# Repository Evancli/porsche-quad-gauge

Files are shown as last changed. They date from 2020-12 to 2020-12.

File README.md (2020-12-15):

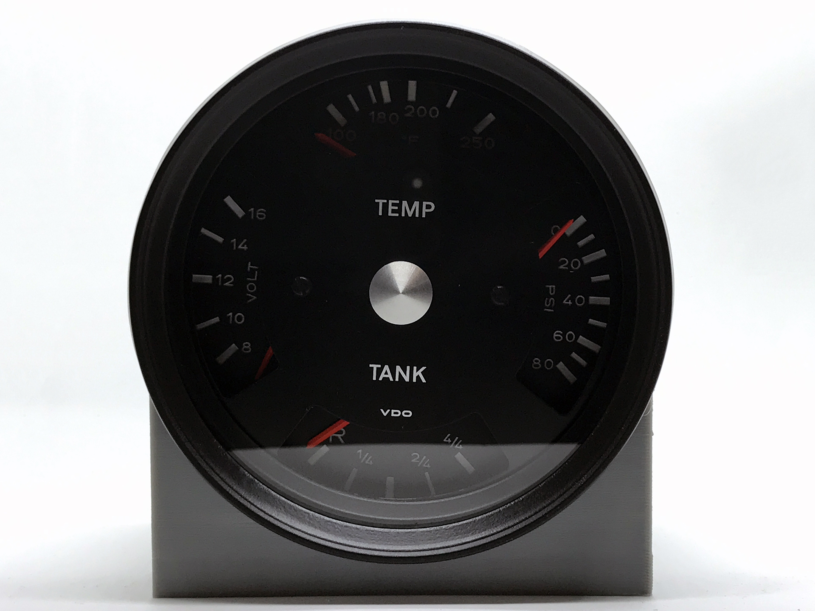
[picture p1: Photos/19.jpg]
Gauge


# QUAD GAUGE FOR A PORSCHE 914
More info [here](https://evanli.com/quad-gauge-for-a-porsche-914/).

## Required Items
This gauge uses salvaged components from a Porsche 944 fuel gauge; the bezel, glass, and face plate. You can used the vintage gauges from the 944 or the corresponding gauges from your 914. It also required two new VDO gauges for voltage and oil pressure.

## Disassembly Tips
It's quite laborious to open these VDO gauges, even with the right tools. A prying spudger and flat implement are needed. Lots of care and attention to not mess up the sheet metal. Be very careful when you pry open the 944 fuel gauge. It's very easy damage the surface finish of the bezel. 

## Processes
The build uses 3D printed parts as well a laser cut and etched parts. 

## License
Shield: [][cc-by-sa]

This work is licensed under a
[Creative Commons Attribution-ShareAlike 4.0 International License][cc-by-sa].

[][cc-by-sa]

[cc-by-sa]: http://creativecommons.org/licenses/by-sa/4.0/
[cc-by-sa-image]: https://licensebuttons.net/l/by-sa/4.0/88x31.png
[cc-by-sa-shield]: https://img.shields.io/badge/License-CC%20BY--SA%204.0-lightgrey.svg

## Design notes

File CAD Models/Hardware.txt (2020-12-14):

4X - 316 Stainless Steel Phillips Flat Head Screws 4-40 Thread Size, 5/16" Long McMaster #:  91500A124
8x - Tapered Heat-Set Inserts for Plastic 4-40 Thread Size, 0.135" Installed Length, Brass McMaster #: 93365A120

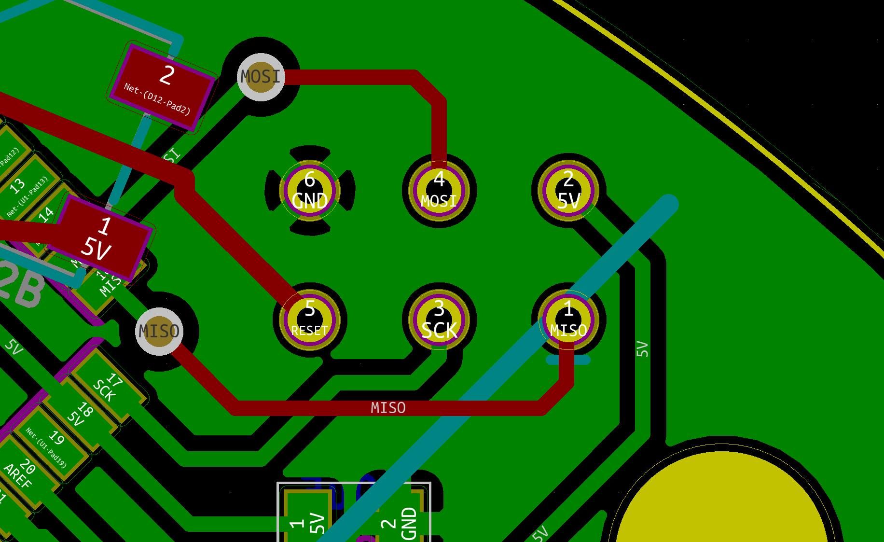
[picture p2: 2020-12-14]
Firmware/Programming Pinout.png

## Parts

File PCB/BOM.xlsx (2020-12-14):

Item # | Qty | Ref Des | Manufacturer | Manufacturer Part Num | Value | Package | Type | Digikey Part Num | Desciption
1 | 11 | QC Connector | TE Connectivity AMP Connectors | 63824-1 |  |  | Through Hole | A29938CT-ND | CONN QC TAB 0.250 SOLDER
2 | 6 | C1, C2, C3, C4, C5, C6 |  |  | 10uF | 0805 | SMT
3 | 1 | C7 |  |  | 0.1uF | 0805 | SMT
4 | 12 | D1, D2, D3, D4, D5, D6, D7, D8, D9, D10, D11, D12 |  | SK6812 RGBW LED |  |  | SMT
5 | 4 or 8 | Gauge Interface Pin (Depends on VDO Gauge Used) | Keystone Electronics | 1223 | 0.267"" (6.78mm) |  | Through Hole | 36-1223-ND | CONN PC PIN CIRC 0.093DIA NICKEL
6 | 4 or 8 | Gauge Interface Pin (Depends on VDO Gauge Used) | Keystone Electronics | 1224 | 0.331"" (8.41mm) |  | Through Hole | 36-1224-ND | CONN PC PIN CIRC 0.093DIA NICKEL
7 | 1 | OSC1 | Kyocera International Inc. | PRQC16.00CR5010X000 | 16MHz | 3-SMD, Non-Standard | SMT | 1253-1675-1-ND | CERAMIC RES 16.0000MHZ 10PF SMD
8 | 4 | R1, R2, R3, R4 |  |  | 1.2K Ohms 5% 1/8W | 0805 | SMT
9 | 3 | R5, R6, R7 |  |  | 1K Ohms 5% 1/8W | 0805 | SMT
10 | 1 | R8 |  |  | 10K Ohms 5% 1/8W | 0805 | SMT
11 | 1 | R9 |  |  | 1M Ohms 5% 1/8W | 0805 | SMT
12 | 4 | R10, R11, R12, R13 |  |  | 392 Ohms 5% 1/8W | 0805 | SMT
13 | 1 | U1 | Microchip Technology | ATMEGA328PB-ANR |  | 32-TQFP | SMT | ATMEGA328PB-ANRCT-ND | IC MCU 8BIT 32KB FLASH 32TQFP
14 | 1 | U2 | Toshiba Semiconductor and Storage | TLP290-4(GB,E) |  | 16-SOIC | SMT | TLP290-4(GBE)-ND | OPTOISOLTR 2.5KV 4CH TRANS 16-SO
15 | 1 | U3 | STMicroelectronics | L4941BDT-TR |  | DPAK | SMT | 497-1168-1-ND | IC REG LINEAR 5V 1A DPAK

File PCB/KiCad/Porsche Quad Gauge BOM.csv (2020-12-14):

Source: | C:\Users\evanc\Dropbox\Projects\Porsche\Quad Gauge\PCB\KiCad\Porsche Quad Gauge.sch
Date: | 12/14/2020 2:12:16 PM
Tool: | Eeschema (5.1.7)-1
Component Count: | 53
Ref | Value | Footprint | Datasheet | Manufacturer | Vendor
12V1 | CONNECTOR_QC_TAB_0.25 | Porsche Quad Gauge:CONNECTOR_QC_TAB-0.25
ALTERNATOR1 | CONNECTOR_QC_TAB_0.25 | Porsche Quad Gauge:CONNECTOR_QC_TAB-0.25
BRAKE_GND1 | CONNECTOR_QC_TAB_0.25 | Porsche Quad Gauge:CONNECTOR_QC_TAB-0.25
C1 | 10uF | Porsche Quad Gauge:0805
C2 | 10uF | Porsche Quad Gauge:0805
C3 | 10uF | Porsche Quad Gauge:0805
C4 | 10uF | Porsche Quad Gauge:0805
C5 | 10uF | Porsche Quad Gauge:0805
C6 | 10uF | Porsche Quad Gauge:0805
C7 | 0.1uF | Porsche Quad Gauge:0805
COOLANT_TEMP1 | CONNECTOR_QC_TAB_0.25 | Porsche Quad Gauge:CONNECTOR_QC_TAB-0.25
COOLANT_TEMP_GAUGE1 | VDO_OLD | Porsche Quad Gauge:VDO_GAUGE_SOCKET
D1 | WS2812B | Porsche Quad Gauge:WS2812B
D2 | WS2812B | Porsche Quad Gauge:WS2812B
D3 | WS2812B | Porsche Quad Gauge:WS2812B
D4 | WS2812B | Porsche Quad Gauge:WS2812B
D5 | WS2812B | Porsche Quad Gauge:WS2812B
D6 | WS2812B | Porsche Quad Gauge:WS2812B
D7 | WS2812B | Porsche Quad Gauge:WS2812B
D8 | WS2812B | Porsche Quad Gauge:WS2812B
D9 | WS2812B | Porsche Quad Gauge:WS2812B
D10 | WS2812B | Porsche Quad Gauge:WS2812B
D11 | WS2812B | Porsche Quad Gauge:WS2812B
D12 | WS2812B | Porsche Quad Gauge:WS2812B
FLASHER1 | CONNECTOR_QC_TAB_0.25 | Porsche Quad Gauge:CONNECTOR_QC_TAB-0.25
FUEL1 | CONNECTOR_QC_TAB_0.25 | Porsche Quad Gauge:CONNECTOR_QC_TAB-0.25
FUEL_GAUGE1 | VDO_OLD | Porsche Quad Gauge:VDO_GAUGE_SOCKET
FUEL_LOW1 | CONNECTOR_QC_TAB_0.25 | Porsche Quad Gauge:CONNECTOR_QC_TAB-0.25
GND1 | CONNECTOR_QC_TAB_0.25 | Porsche Quad Gauge:CONNECTOR_QC_TAB-0.25
J1 | AVR_SPI_PROG_3X2TESTPOINTS | Porsche Quad Gauge:2X3_TEST_POINTS
J2 | CONN_02 | Porsche Quad Gauge:1X02
LIGHT1 | CONNECTOR_QC_TAB_0.25 | Porsche Quad Gauge:CONNECTOR_QC_TAB-0.25
OIL_LOW1 | CONNECTOR_QC_TAB_0.25 | Porsche Quad Gauge:CONNECTOR_QC_TAB-0.25
OIL_PRESSURE1 | CONNECTOR_QC_TAB_0.25 | Porsche Quad Gauge:CONNECTOR_QC_TAB-0.25
OIL_PRESSURE_GAUGE1 | VDO_NEW | Porsche Quad Gauge:VDO_NEW_GAUGE_SOCKET
OSC1 | PRQC16.00SR1010V00L | Porsche Quad Gauge:3-SMD
R1 | 1.2K | Porsche Quad Gauge:0805
R2 | 1.2K | Porsche Quad Gauge:0805
R3 | 1.2K | Porsche Quad Gauge:0805
R4 | 1.2K | Porsche Quad Gauge:0805
R5 | 1k | Porsche Quad Gauge:0805
R6 | 1k | Porsche Quad Gauge:0805
R7 | 1k | Porsche Quad Gauge:0805
R8 | 10K | Porsche Quad Gauge:0805
R9 | 1M | Porsche Quad Gauge:0805
R10 | 392 | Porsche Quad Gauge:0805
R11 | 392 | Porsche Quad Gauge:0805
R12 | 392 | Porsche Quad Gauge:0805
R13 | 392 | Porsche Quad Gauge:0805
U1 | ATMEGA328P_TQFP | Porsche Quad Gauge:TQFP32-08
U2 | TLP290-4 | Porsche Quad Gauge:SO16
U3 | L4941BDT-TR | Porsche Quad Gauge:D-PAK_TO252AA
VOLTAGE_GAUGE1 | VDO_NEW | Porsche Quad Gauge:VDO_NEW_GAUGE_SOCKET

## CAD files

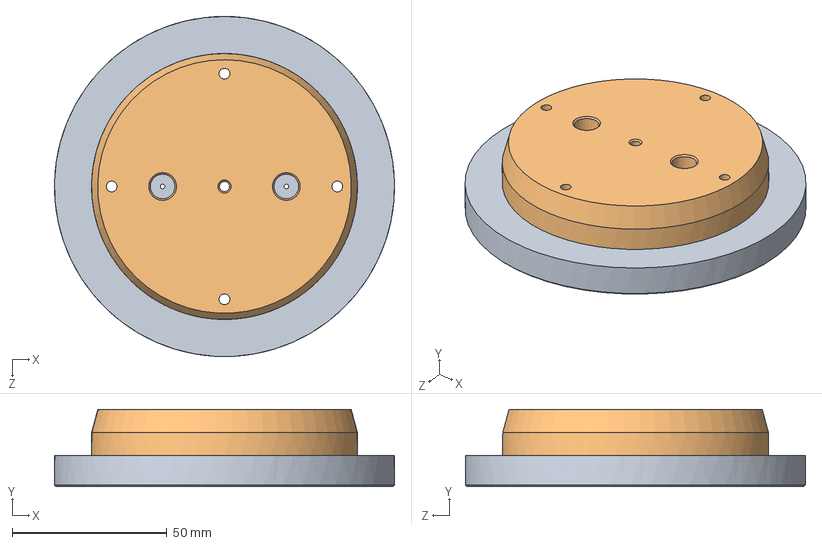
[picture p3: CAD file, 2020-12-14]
Tooling/SLD/Jig.SLDASM
110.0 x 25.0 x 110.0 mm
Jig Base
Drill Jig 3mm

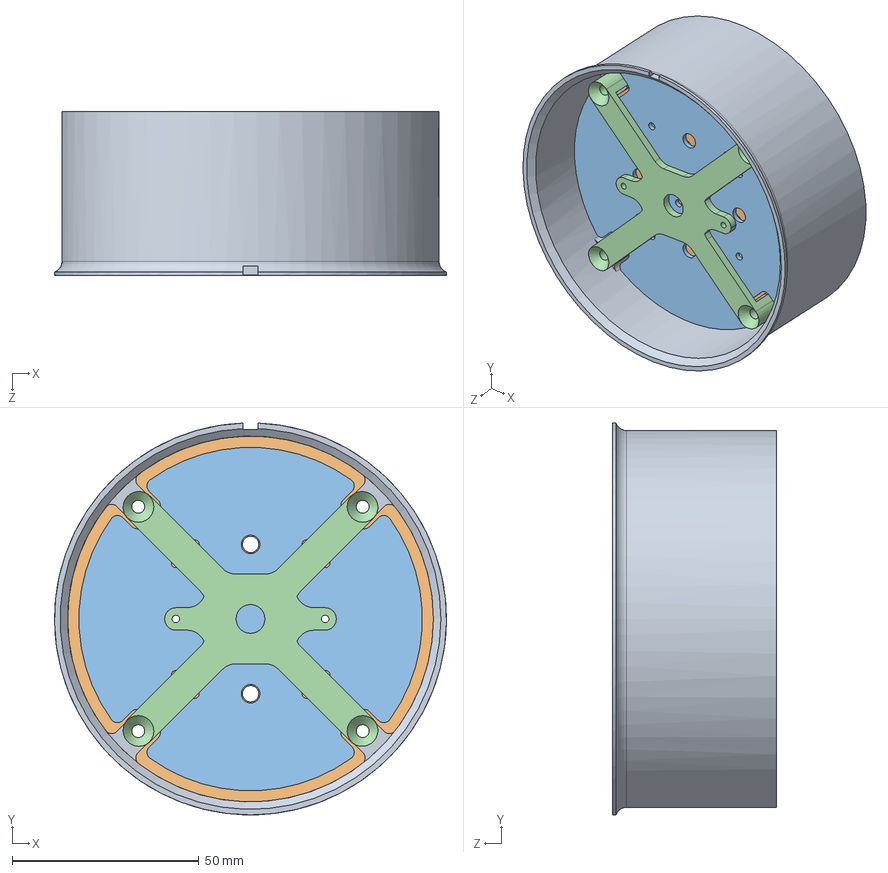
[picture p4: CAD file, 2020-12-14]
CAD Models/SLD/Gauge.SLDASM
105.0 x 105.0 x 44.0 mm
Gauge Shell
PCB
Marking Panel
Panel Mount

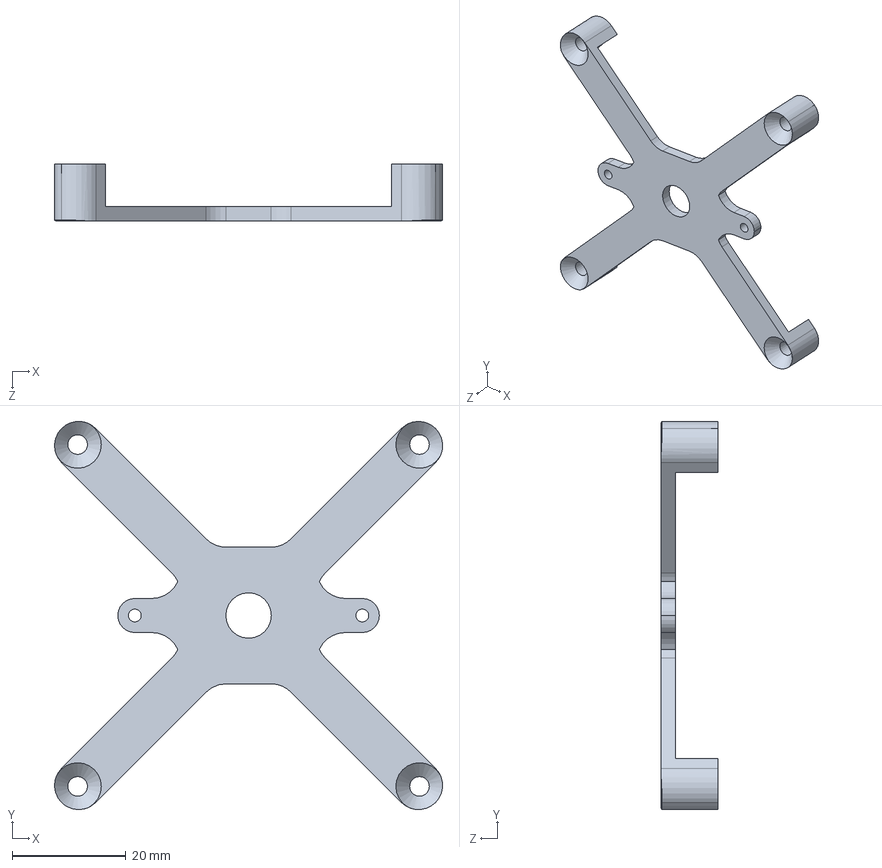
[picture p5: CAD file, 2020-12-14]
CAD Models/SLD/Panel Mount.SLDPRT
68.2 x 68.3 x 10.0 mm

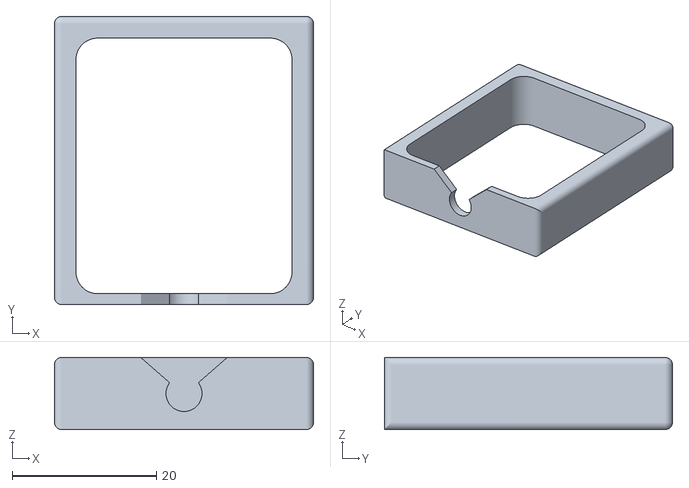
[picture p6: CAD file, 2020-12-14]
Tooling/STL/Needle Puller.STL
36.0 x 40.0 x 10.0

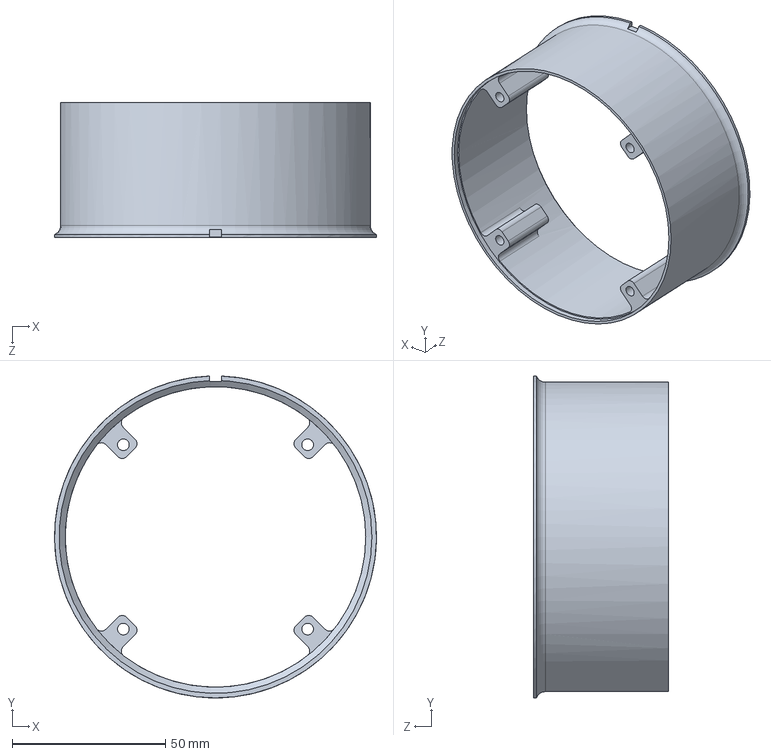
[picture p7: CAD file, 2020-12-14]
CAD Models/SLD/Gauge Shell.SLDPRT
105.0 x 105.0 x 44.0 mm

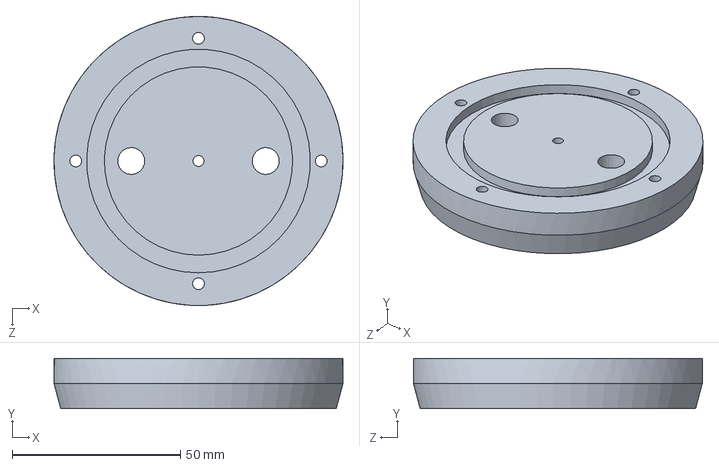
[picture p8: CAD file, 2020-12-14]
Tooling/SLD/Drill Jig 3mm.SLDPRT
86.0 x 15.0 x 86.0 mm

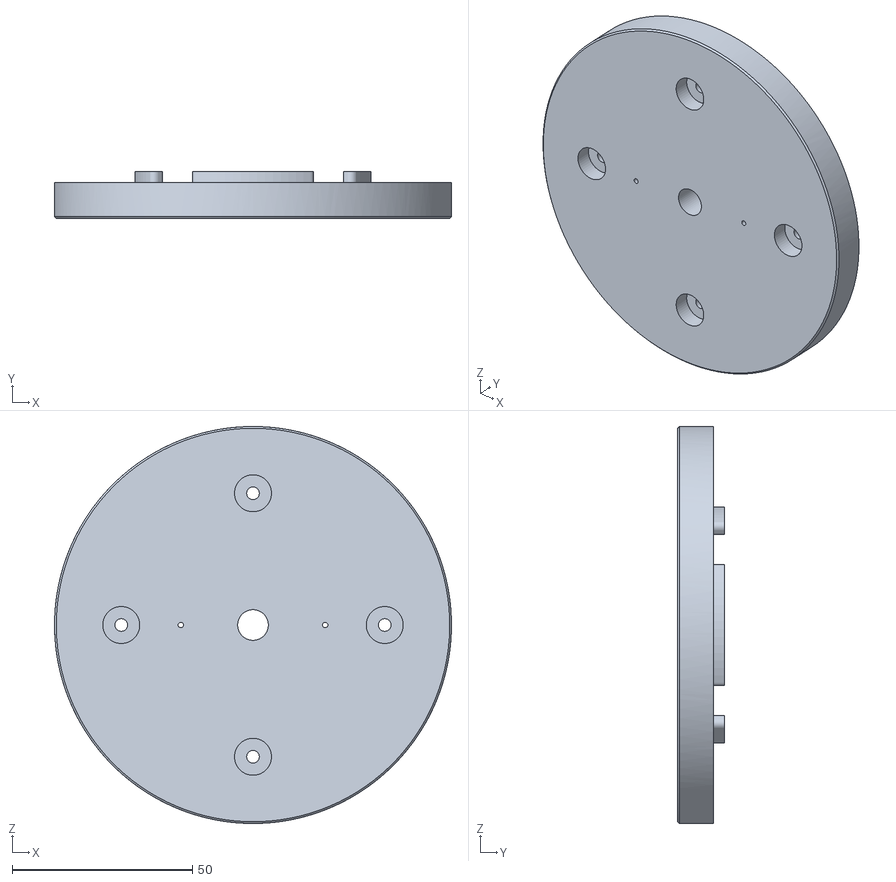
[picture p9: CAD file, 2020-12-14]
Tooling/STL/Jig Base.STL
110.0 x 13.0 x 110.0

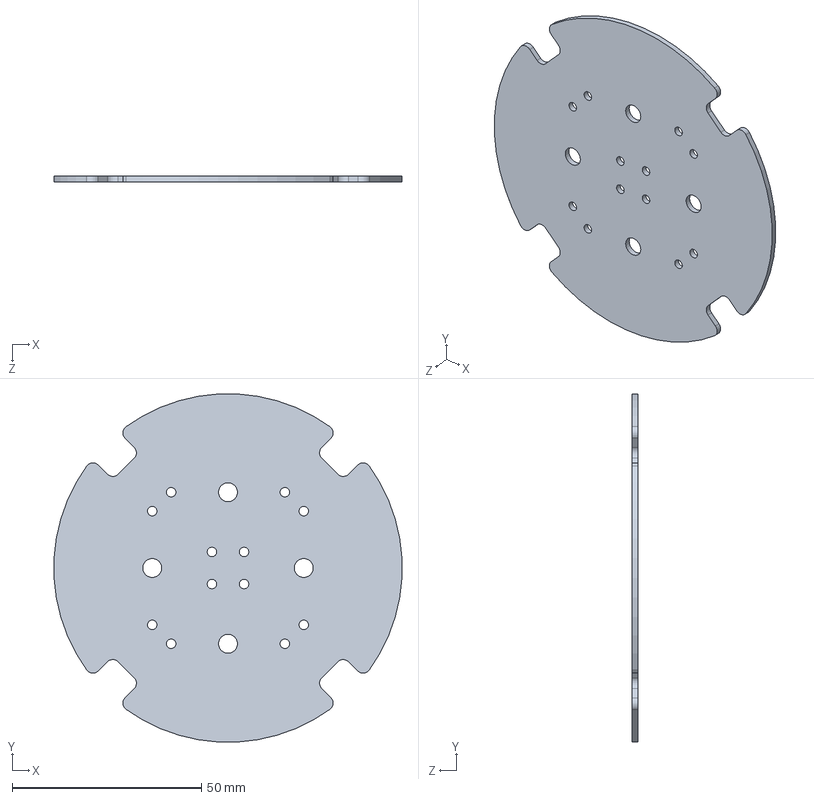
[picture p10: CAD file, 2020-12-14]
CAD Models/SLD/Marking Panel.SLDPRT
91.9 x 91.9 x 1.50 mm

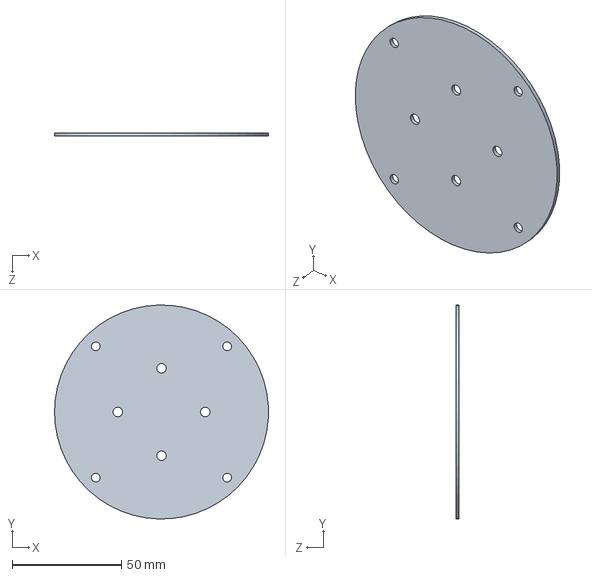
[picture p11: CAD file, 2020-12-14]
CAD Models/SLD/PCB.SLDPRT
98.0 x 98.0 x 1.60 mm

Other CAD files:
CAD Models/STL/Panel Mount v0.3.STL
CAD Models/STL/Gauge Shell v0.5.STL
Tooling/SLD/Jig Base.SLDPRT
Tooling/STL/Drill Jig 7mm.STL
Tooling/SLD/Needle Puller.SLDPRT
Tooling/STL/Drill Jig 3mm.STL
Tooling/SLD/Drill Jig 7mm.SLDPRT

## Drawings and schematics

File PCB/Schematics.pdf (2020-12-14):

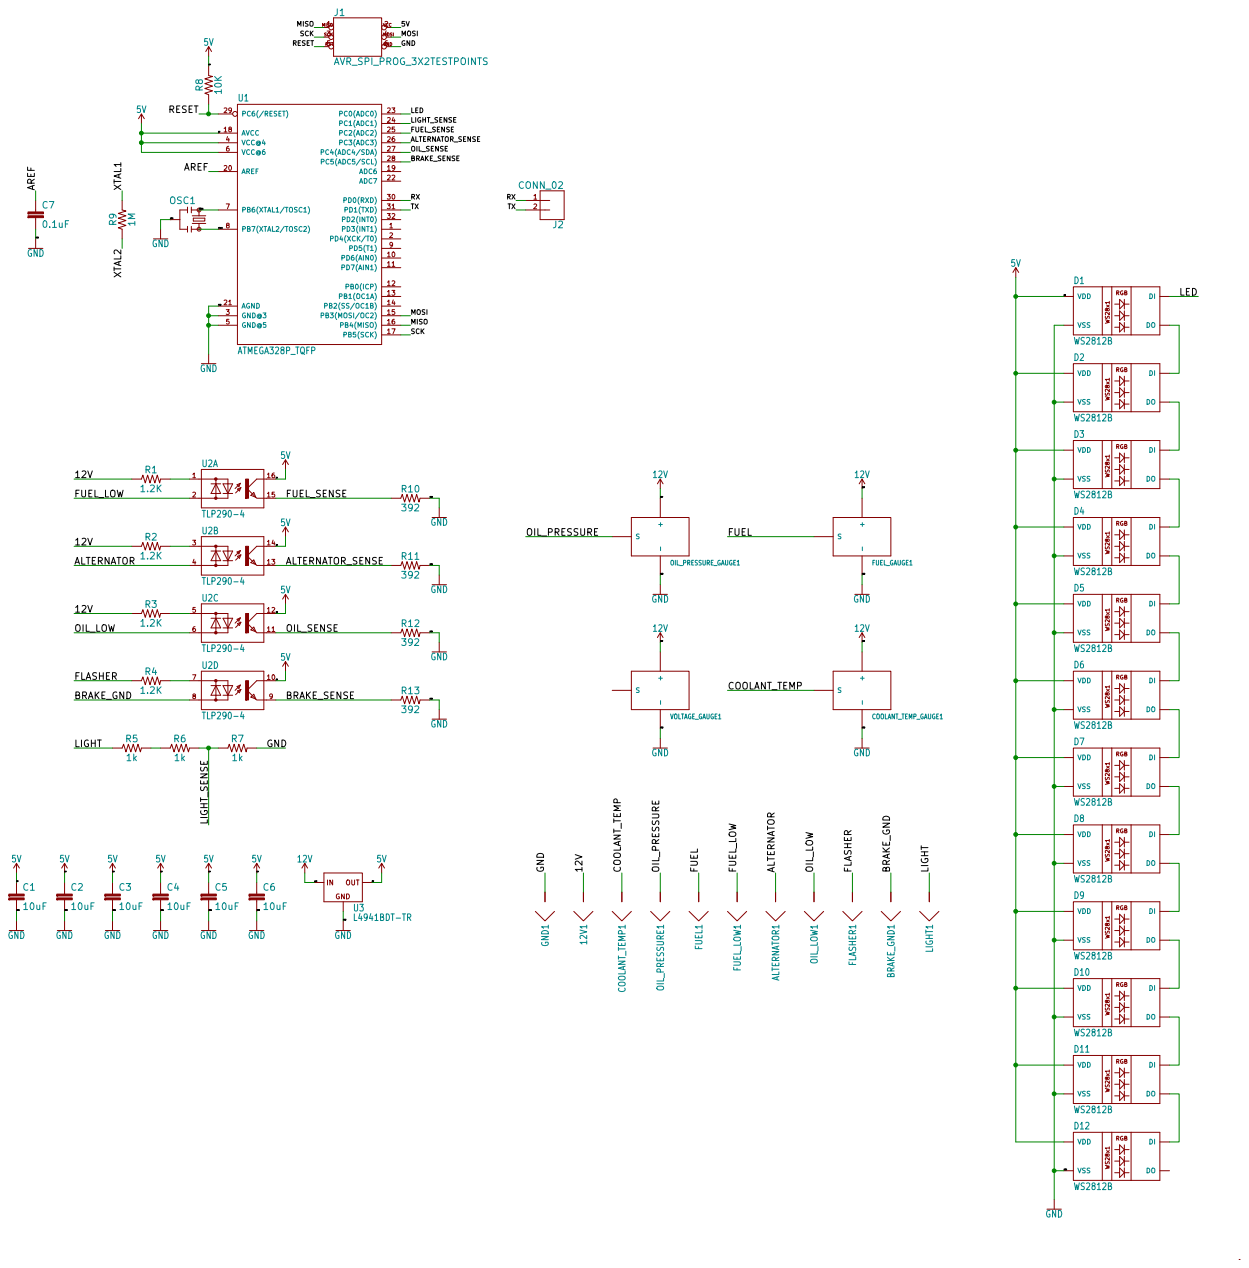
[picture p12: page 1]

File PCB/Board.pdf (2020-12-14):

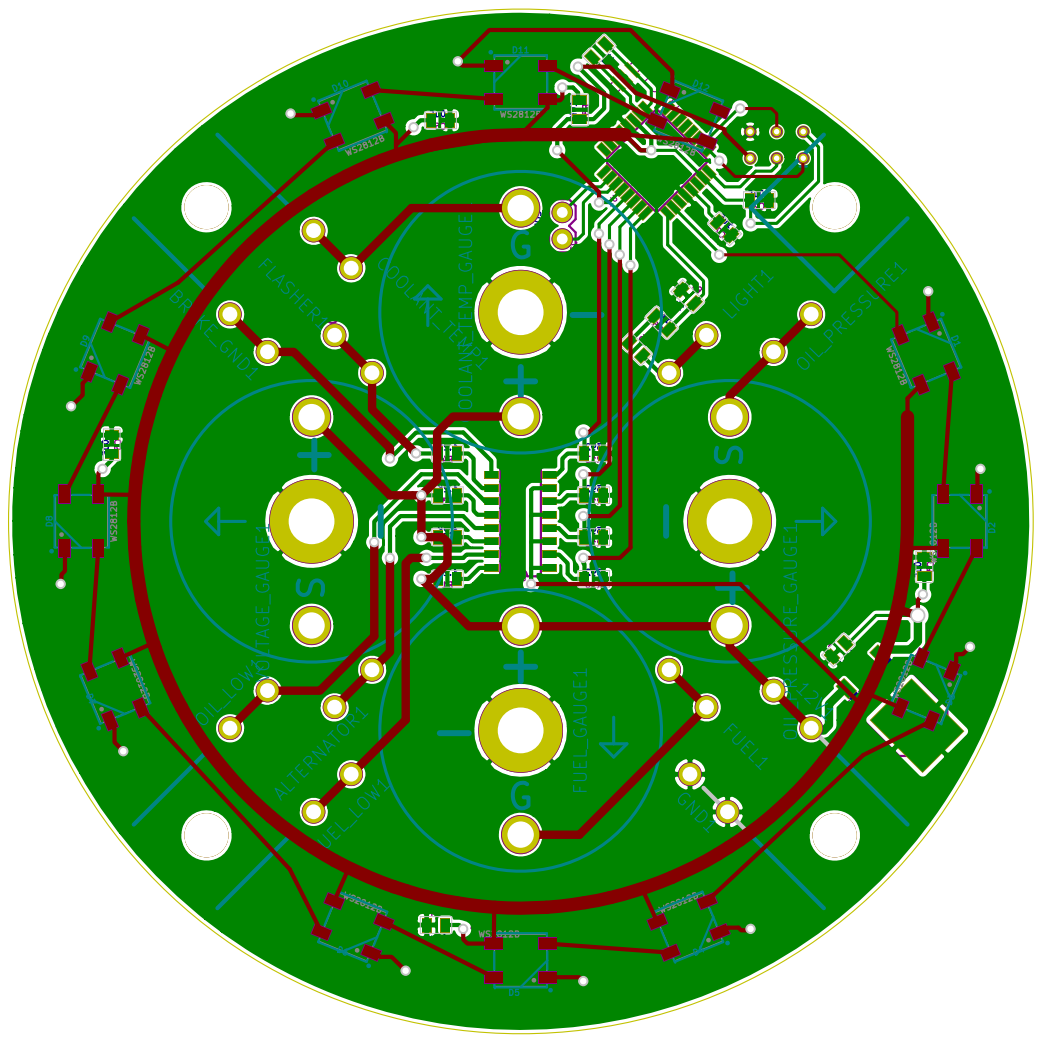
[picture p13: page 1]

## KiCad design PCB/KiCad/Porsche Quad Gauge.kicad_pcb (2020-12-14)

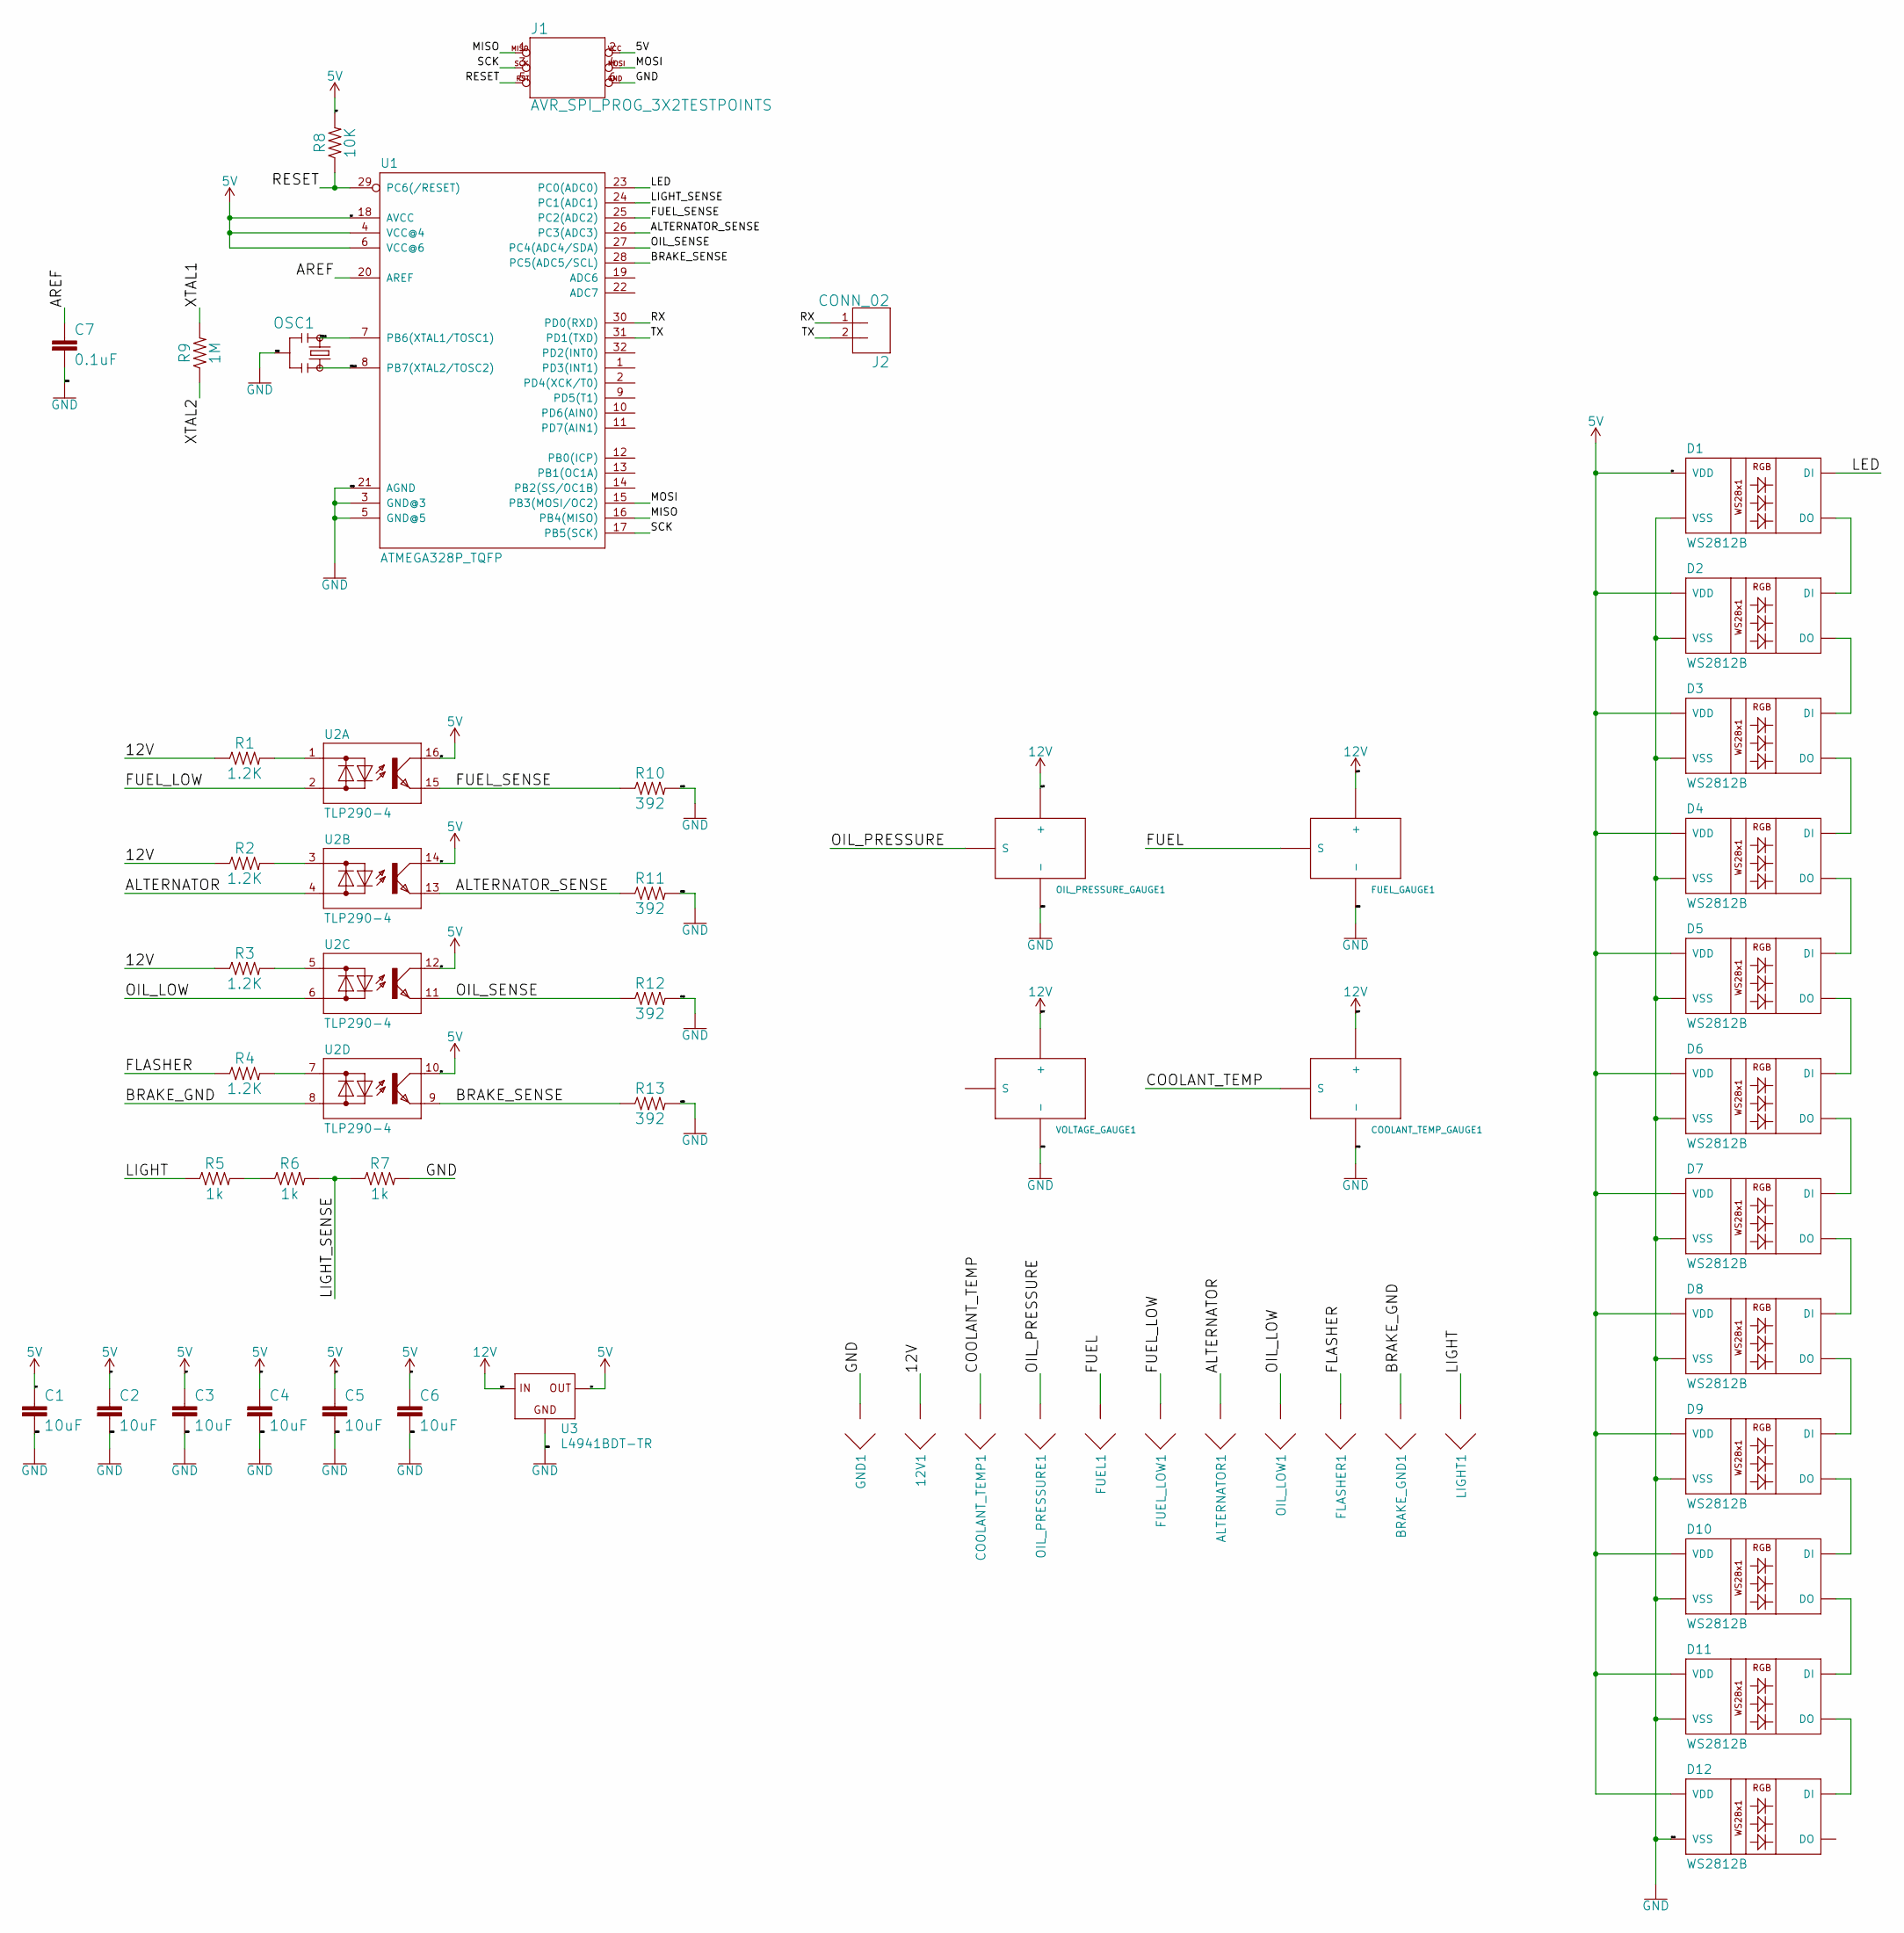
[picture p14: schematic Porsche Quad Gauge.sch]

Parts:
12V1: CONNECTOR_QC_TAB_0.25; CONNECTOR_QC_TAB-0.25
ALTERNATOR1: CONNECTOR_QC_TAB_0.25; CONNECTOR_QC_TAB-0.25
BRAKE_GND1: CONNECTOR_QC_TAB_0.25; CONNECTOR_QC_TAB-0.25
C1, C2, C3, C4, C5, C6: 10uF; 0805
C7: 0.1uF; 0805
COOLANT_TEMP1: CONNECTOR_QC_TAB_0.25; CONNECTOR_QC_TAB-0.25
COOLANT_TEMP_GAUGE1: VDO_OLD; VDO_GAUGE_SOCKET
D1, D2, D3, D4, D5, D6, D7, D8, D9, D10, D11, D12: WS2812B
FLASHER1: CONNECTOR_QC_TAB_0.25; CONNECTOR_QC_TAB-0.25
FUEL1: CONNECTOR_QC_TAB_0.25; CONNECTOR_QC_TAB-0.25
FUEL_GAUGE1: VDO_OLD; VDO_GAUGE_SOCKET
FUEL_LOW1: CONNECTOR_QC_TAB_0.25; CONNECTOR_QC_TAB-0.25
GND1: CONNECTOR_QC_TAB_0.25; CONNECTOR_QC_TAB-0.25
J1: AVR_SPI_PROG_3X2TESTPOINTS; 2X3_TEST_POINTS
J2: CONN_02; 1X02
LIGHT1: CONNECTOR_QC_TAB_0.25; CONNECTOR_QC_TAB-0.25
OIL_LOW1: CONNECTOR_QC_TAB_0.25; CONNECTOR_QC_TAB-0.25
OIL_PRESSURE1: CONNECTOR_QC_TAB_0.25; CONNECTOR_QC_TAB-0.25
OIL_PRESSURE_GAUGE1: VDO_NEW; VDO_NEW_GAUGE_SOCKET
OSC1: PRQC16.00SR1010V00L; 3-SMD
R1, R2, R3, R4: 1.2K; 0805
R5, R6, R7: 1k; 0805
R8: 10K; 0805
R9: 1M; 0805
R10, R11, R12, R13: 392; 0805
U1: ATMEGA328P_TQFP; TQFP32-08
U2: TLP290-4; SO16
U3: L4941BDT-TR; D-PAK_TO252AA
VOLTAGE_GAUGE1: VDO_NEW; VDO_NEW_GAUGE_SOCKET

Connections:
5V: C1.1, C2.1, C3.1, C4.1, C5.1, C6.1, D1.1 (VDD), D2.1 (VDD), D3.1 (VDD), D4.1 (VDD), D5.1 (VDD), D6.1 (VDD), D7.1 (VDD), D8.1 (VDD), D9.1 (VDD), D10.1 (VDD), D11.1 (VDD), D12.1 (VDD), J1.2, R8.2, U1.4 (VCC@4), U1.6 (VCC@6), U1.18 (AVCC), U2.10 (C), U2.12 (C), U2.14 (C), U2.16 (C), U3.3 (OUT)
12V: 12V1.S1, 12V1.S2, COOLANT_TEMP_GAUGE1.12V (+), FUEL_GAUGE1.12V (+), OIL_PRESSURE_GAUGE1.12V (+), R1.1, R2.1, R3.1, U3.1 (IN), VOLTAGE_GAUGE1.12V (+)
/ALTERNATOR: ALTERNATOR1.S1, ALTERNATOR1.S2, U2.4 (AC2)
/ALTERNATOR_SENSE: R11.1, U1.26 (PC3(ADC3)), U2.13 (E)
/AREF: C7.1, U1.20 (AREF)
/BRAKE_GND: BRAKE_GND1.S1, BRAKE_GND1.S2, U2.8 (AC2)
/BRAKE_SENSE: R13.1, U1.28 (PC5(ADC5/SCL)), U2.9 (E)
/COOLANT_TEMP: COOLANT_TEMP1.S1, COOLANT_TEMP1.S2, COOLANT_TEMP_GAUGE1.SIGNAL (S)
/FLASHER: FLASHER1.S1, FLASHER1.S2, R4.1
/FUEL: FUEL1.S1, FUEL1.S2, FUEL_GAUGE1.SIGNAL (S)
/FUEL_LOW: FUEL_LOW1.S1, FUEL_LOW1.S2, U2.2 (AC2)
/FUEL_SENSE: R10.1, U1.25 (PC2(ADC2)), U2.15 (E)
/LED: D1.4 (DI), U1.23 (PC0(ADC0))
/LIGHT: LIGHT1.S1, LIGHT1.S2, R5.1
/LIGHT_SENSE: R6.2, R7.1, U1.24 (PC1(ADC1))
/MISO: J1.1, U1.16 (PB4(MISO))
/MOSI: J1.4, U1.15 (PB3(MOSI/OC2))
/OIL_LOW: OIL_LOW1.S1, OIL_LOW1.S2, U2.6 (AC2)
/OIL_PRESSURE: OIL_PRESSURE1.S1, OIL_PRESSURE1.S2, OIL_PRESSURE_GAUGE1.SIGNAL (S)
/OIL_SENSE: R12.1, U1.27 (PC4(ADC4/SDA)), U2.11 (E)
/RESET: J1.5, R8.1, U1.29 (PC6(/RESET))
/RX: J2.1, U1.30 (PD0(RXD))
/SCK: J1.3, U1.17 (PB5(SCK))
/TX: J2.2, U1.31 (PD1(TXD))
/XTAL1: OSC1.XTAL1 (1), R9.2, U1.7 (PB6(XTAL1/TOSC1))
/XTAL2: OSC1.XTAL2 (3), R9.1, U1.8 (PB7(XTAL2/TOSC2))
GND: C1.2, C2.2, C3.2, C4.2, C5.2, C6.2, C7.2, COOLANT_TEMP_GAUGE1.GND (-), D1.3 (VSS), D2.3 (VSS), D3.3 (VSS), D4.3 (VSS), D5.3 (VSS), D6.3 (VSS), D7.3 (VSS), D8.3 (VSS), D9.3 (VSS), D10.3 (VSS), D11.3 (VSS), D12.3 (VSS), FUEL_GAUGE1.GND (-), GND1.S1, GND1.S2, J1.6, OIL_PRESSURE_GAUGE1.GND (-), OSC1.GND (2), R7.2, R10.2, R11.2, R12.2, R13.2, U1.3 (GND@3), U1.5 (GND@5), U1.21 (AGND), U3.2 (GND), VOLTAGE_GAUGE1.GND (-)
unnamed: D1.2 (DO), D2.4 (DI)
unnamed: D2.2 (DO), D3.4 (DI)
unnamed: D3.2 (DO), D4.4 (DI)
unnamed: D4.2 (DO), D5.4 (DI)
unnamed: D5.2 (DO), D6.4 (DI)
unnamed: D6.2 (DO), D7.4 (DI)
unnamed: D7.2 (DO), D8.4 (DI)
unnamed: D8.2 (DO), D9.4 (DI)
unnamed: D10.2 (DO), D11.4 (DI)
unnamed: D9.2 (DO), D10.4 (DI)
unnamed: D11.2 (DO), D12.4 (DI)
unnamed: R1.2, U2.1 (AC1)
unnamed: R2.2, U2.3 (AC1)
unnamed: R3.2, U2.5 (AC1)
unnamed: R4.2, U2.7 (AC1)
unnamed: R5.2, R6.1

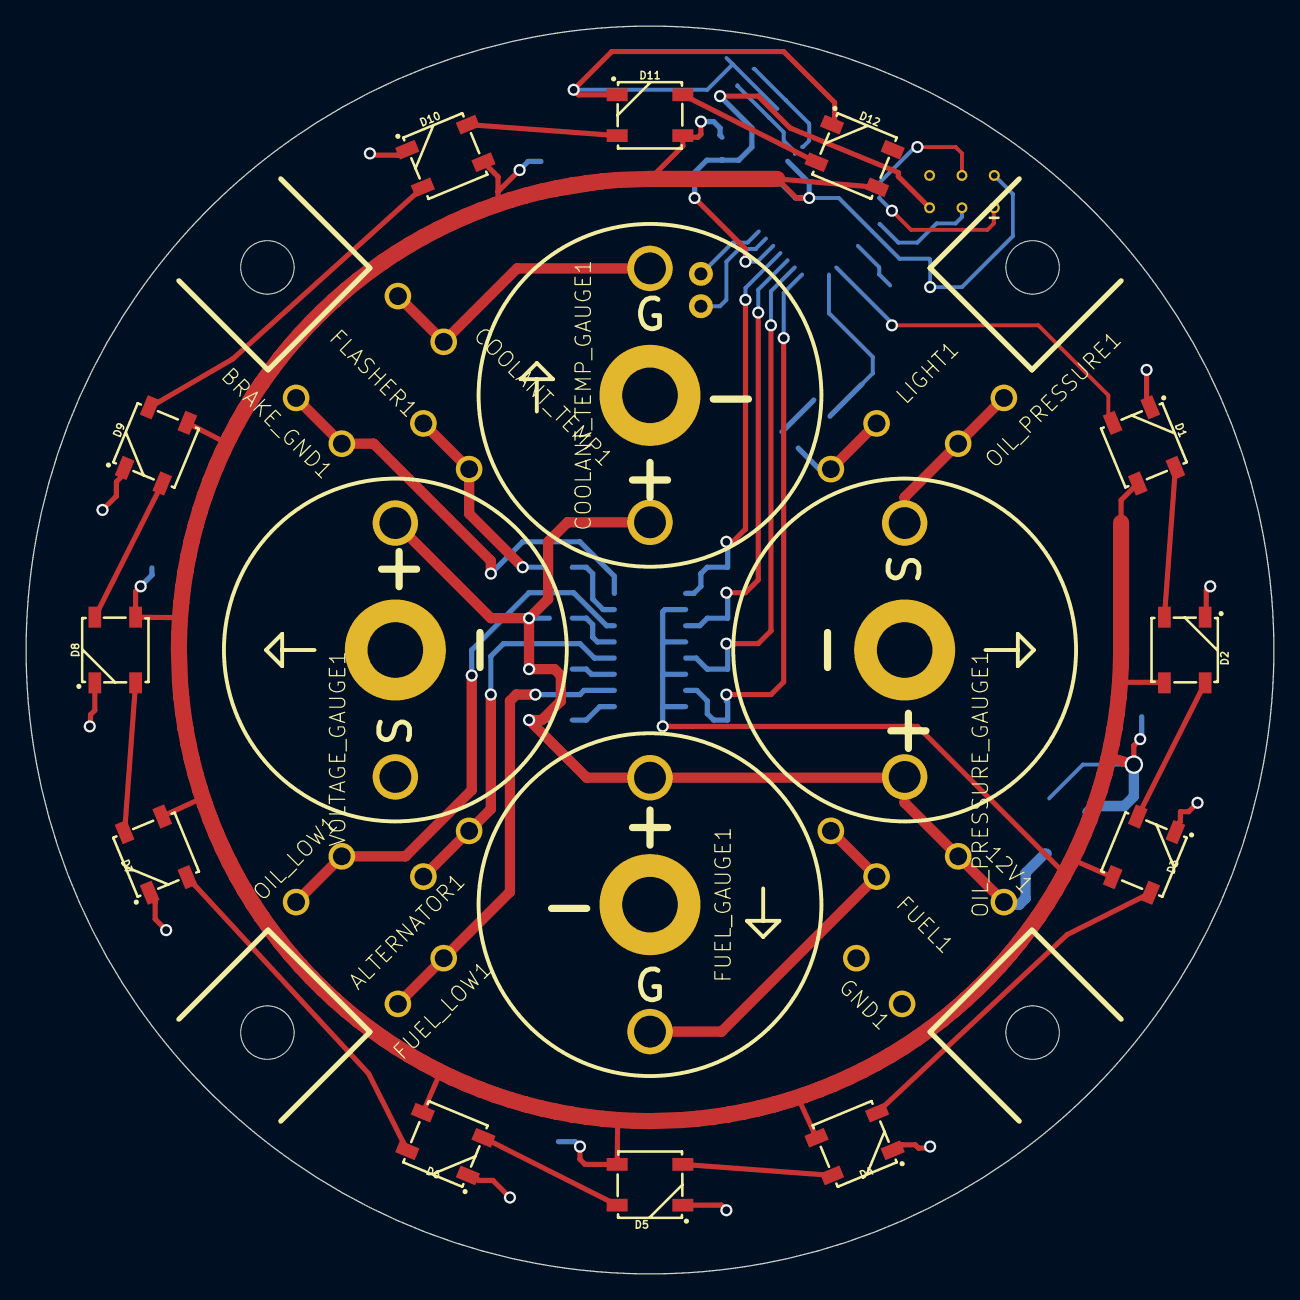
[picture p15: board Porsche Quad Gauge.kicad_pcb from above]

Board: 2 copper layers, 98.0 x 98.0 mm, 57 parts (0 on the bottom side), 43 nets.

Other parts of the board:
@HOLE0, @HOLE1, @HOLE2, @HOLE3: (no value)

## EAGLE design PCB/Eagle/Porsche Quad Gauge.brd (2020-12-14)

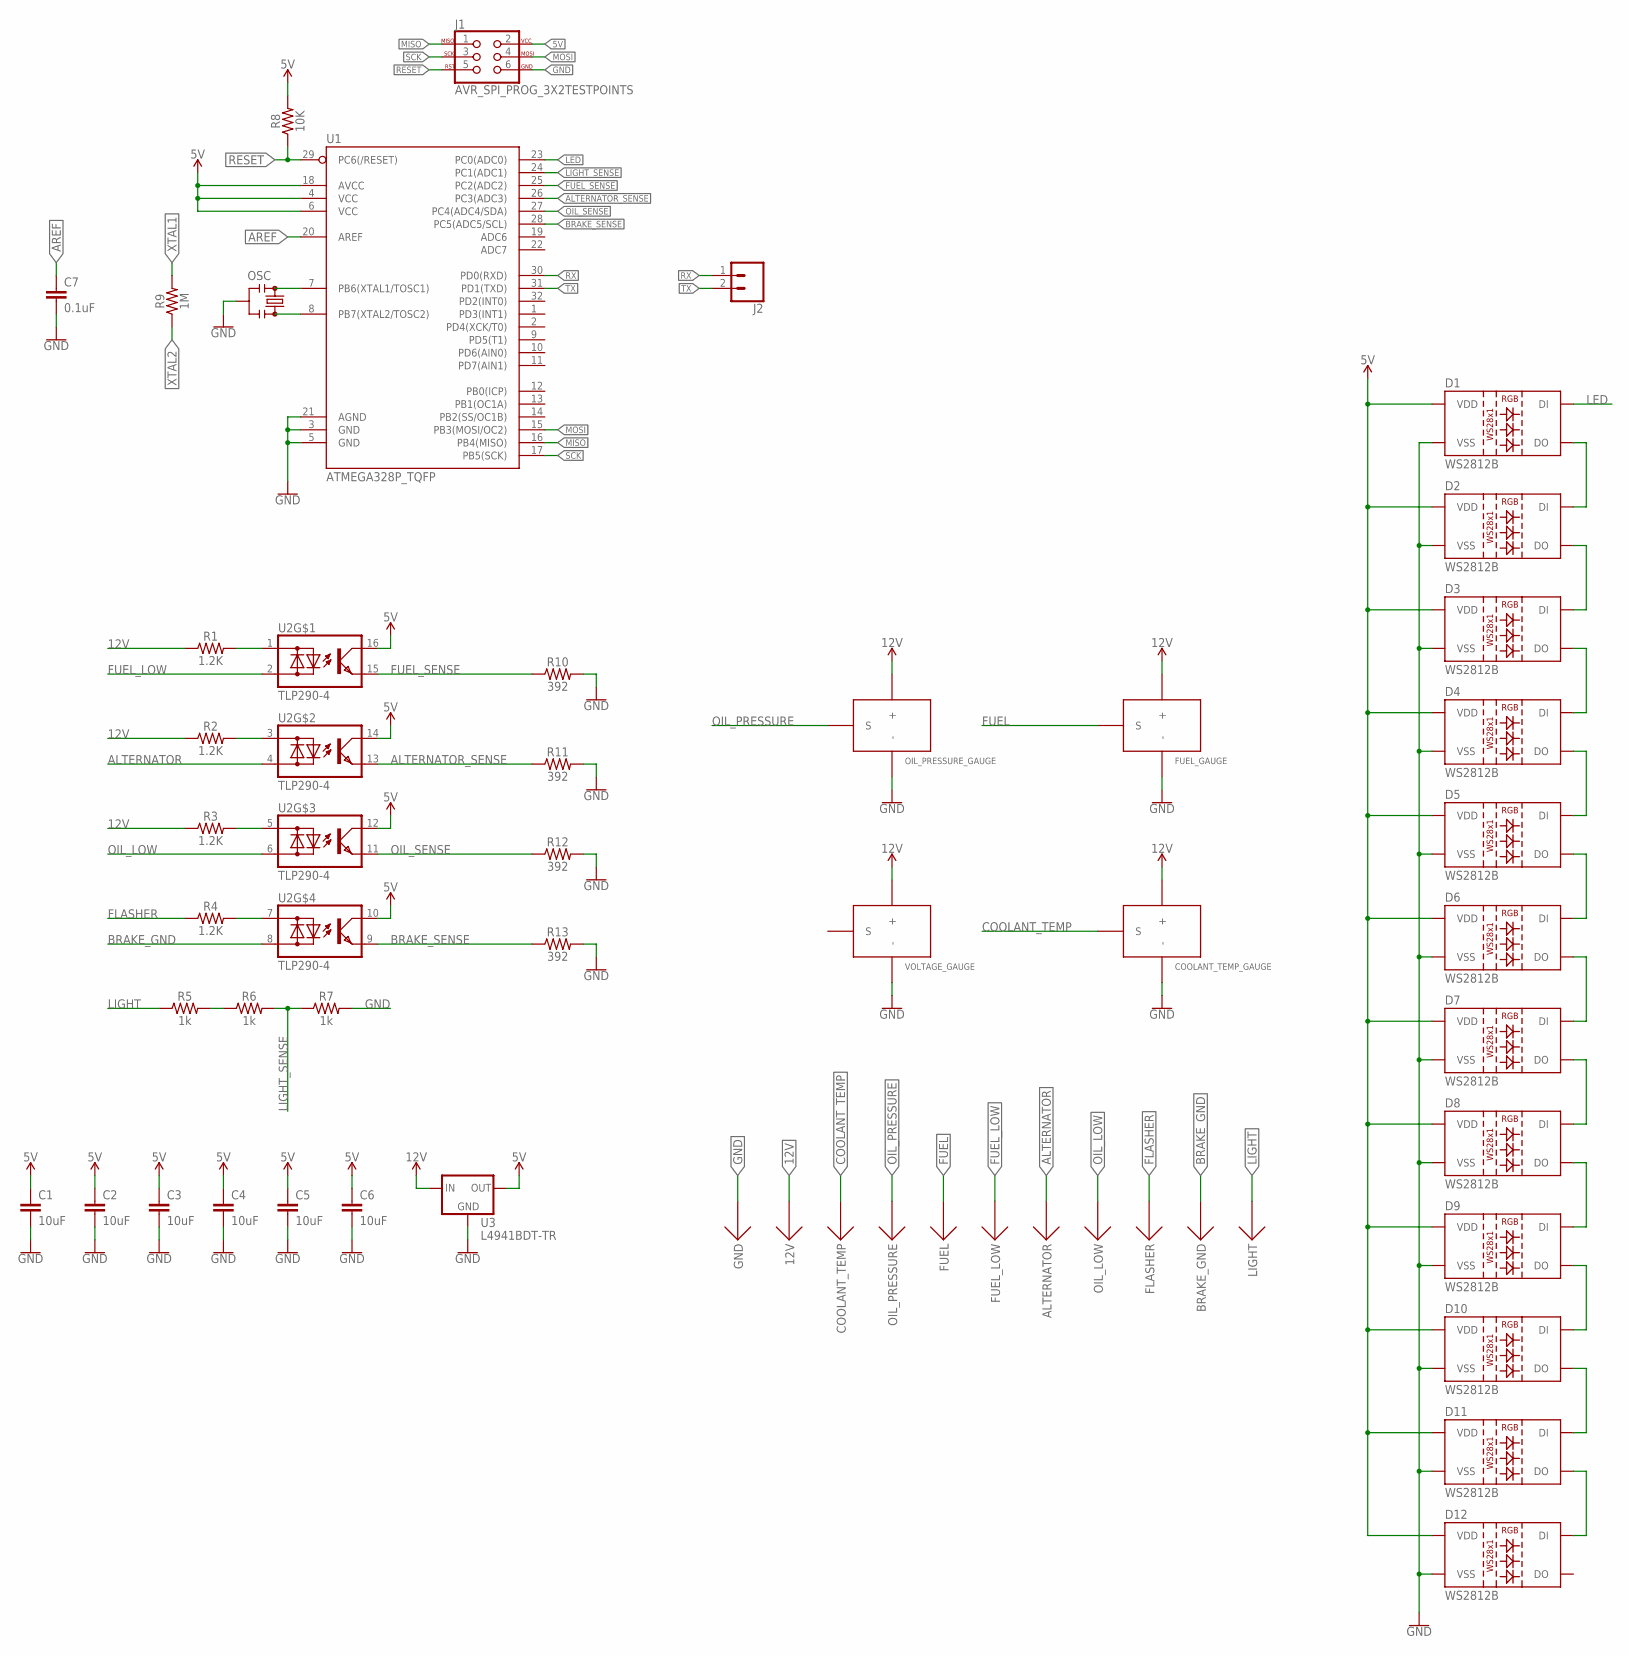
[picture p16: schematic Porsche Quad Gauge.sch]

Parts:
12V: CONNECTOR_QC_TAB_0.25; CONNECTOR_QC_TAB-0.25
ALTERNATOR: CONNECTOR_QC_TAB_0.25; CONNECTOR_QC_TAB-0.25
BRAKE_GND: CONNECTOR_QC_TAB_0.25; CONNECTOR_QC_TAB-0.25
C1, C2, C3, C4, C5, C6: 10uF; 0805
C7: 0.1uF; 0805
COOLANT_TEMP: CONNECTOR_QC_TAB_0.25; CONNECTOR_QC_TAB-0.25
COOLANT_TEMP_GAUGE: VDO_OLD; VDO_GAUGE_SOCKET
D1, D2, D3, D4, D5, D6, D7, D8, D9, D10, D11, D12: WS2812B
FLASHER: CONNECTOR_QC_TAB_0.25; CONNECTOR_QC_TAB-0.25
FUEL: CONNECTOR_QC_TAB_0.25; CONNECTOR_QC_TAB-0.25
FUEL_GAUGE: VDO_OLD; VDO_GAUGE_SOCKET
FUEL_LOW: CONNECTOR_QC_TAB_0.25; CONNECTOR_QC_TAB-0.25
GND: CONNECTOR_QC_TAB_0.25; CONNECTOR_QC_TAB-0.25
J1: AVR_SPI_PROG_3X2TESTPOINTS; 2X3_TEST_POINTS
J2: CONN_02; 1X02
LIGHT: CONNECTOR_QC_TAB_0.25; CONNECTOR_QC_TAB-0.25
OIL_LOW: CONNECTOR_QC_TAB_0.25; CONNECTOR_QC_TAB-0.25
OIL_PRESSURE: CONNECTOR_QC_TAB_0.25; CONNECTOR_QC_TAB-0.25
OIL_PRESSURE_GAUGE: VDO_NEW; VDO_NEW_GAUGE_SOCKET
OSC: PRQC16.00SR1010V00L; 3-SMD
R1, R2, R3, R4: 1.2K; 0805
R5, R6, R7: 1k; 0805
R8: 10K; 0805
R9: 1M; 0805
R10, R11, R12, R13: 392; 0805
U1: ATMEGA328P_TQFP; TQFP32-08
U2: TLP290-4; SO16
U3: L4941BDT-TR; D-PAK_TO252AA
VOLTAGE_GAUGE: VDO_NEW; VDO_NEW_GAUGE_SOCKET

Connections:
5V: C1.1, C2.1, C3.1, C4.1, C5.1, C6.1, D1.1 (VDD), D2.1 (VDD), D3.1 (VDD), D4.1 (VDD), D5.1 (VDD), D6.1 (VDD), D7.1 (VDD), D8.1 (VDD), D9.1 (VDD), D10.1 (VDD), D11.1 (VDD), D12.1 (VDD), J1.2, R8.2, U1.4 (VCC), U1.6 (VCC), U1.18 (AVCC), U2.10 (C), U2.12 (C), U2.14 (C), U2.16 (C), U3.3 (OUT)
12V: 12V.S1, 12V.S2, COOLANT_TEMP_GAUGE.12V (+), FUEL_GAUGE.12V (+), OIL_PRESSURE_GAUGE.12V (+), R1.1, R2.1, R3.1, U3.1 (IN), VOLTAGE_GAUGE.12V (+)
ALTERNATOR: ALTERNATOR.S1, ALTERNATOR.S2, U2.4 (AC2)
ALTERNATOR_SENSE: R11.1, U1.26 (PC3(ADC3)), U2.13 (E)
AREF: C7.1, U1.20 (AREF)
BRAKE_GND: BRAKE_GND.S1, BRAKE_GND.S2, U2.8 (AC2)
BRAKE_SENSE: R13.1, U1.28 (PC5(ADC5/SCL)), U2.9 (E)
COOLANT_TEMP: COOLANT_TEMP.S1, COOLANT_TEMP.S2, COOLANT_TEMP_GAUGE.SIGNAL (S)
FLASHER: FLASHER.S1, FLASHER.S2, R4.1
FUEL: FUEL.S1, FUEL.S2, FUEL_GAUGE.SIGNAL (S)
FUEL_LOW: FUEL_LOW.S1, FUEL_LOW.S2, U2.2 (AC2)
FUEL_SENSE: R10.1, U1.25 (PC2(ADC2)), U2.15 (E)
GND: C1.2, C2.2, C3.2, C4.2, C5.2, C6.2, C7.2, COOLANT_TEMP_GAUGE.GND (-), D1.3 (VSS), D2.3 (VSS), D3.3 (VSS), D4.3 (VSS), D5.3 (VSS), D6.3 (VSS), D7.3 (VSS), D8.3 (VSS), D9.3 (VSS), D10.3 (VSS), D11.3 (VSS), D12.3 (VSS), FUEL_GAUGE.GND (-), GND.S1, GND.S2, J1.6, OIL_PRESSURE_GAUGE.GND (-), OSC.GND (2), R7.2, R10.2, R11.2, R12.2, R13.2, U1.3 (GND), U1.5 (GND), U1.21 (AGND), U3.2 (GND), VOLTAGE_GAUGE.GND (-)
LED: D1.4 (DI), U1.23 (PC0(ADC0))
LIGHT: LIGHT.S1, LIGHT.S2, R5.1
LIGHT_SENSE: R6.2, R7.1, U1.24 (PC1(ADC1))
MISO: J1.1, U1.16 (PB4(MISO))
MOSI: J1.4, U1.15 (PB3(MOSI/OC2))
unnamed: R1.2, U2.1 (AC1)
unnamed: R5.2, R6.1
unnamed: R2.2, U2.3 (AC1)
unnamed: D1.2 (DO), D2.4 (DI)
unnamed: D2.2 (DO), D3.4 (DI)
unnamed: D3.2 (DO), D4.4 (DI)
unnamed: D4.2 (DO), D5.4 (DI)
unnamed: D5.2 (DO), D6.4 (DI)
unnamed: D6.2 (DO), D7.4 (DI)
unnamed: D7.2 (DO), D8.4 (DI)
unnamed: D8.2 (DO), D9.4 (DI)
unnamed: D9.2 (DO), D10.4 (DI)
unnamed: D10.2 (DO), D11.4 (DI)
unnamed: D11.2 (DO), D12.4 (DI)
unnamed: R3.2, U2.5 (AC1)
unnamed: R4.2, U2.7 (AC1)
OIL_LOW: OIL_LOW.S1, OIL_LOW.S2, U2.6 (AC2)
OIL_PRESSURE: OIL_PRESSURE.S1, OIL_PRESSURE.S2, OIL_PRESSURE_GAUGE.SIGNAL (S)
OIL_SENSE: R12.1, U1.27 (PC4(ADC4/SDA)), U2.11 (E)
RESET: J1.5, R8.1, U1.29 (PC6(/RESET))
RX: J2.1, U1.30 (PD0(RXD))
SCK: J1.3, U1.17 (PB5(SCK))
TX: J2.2, U1.31 (PD1(TXD))
XTAL1: OSC.XTAL1 (1), R9.2, U1.7 (PB6(XTAL1/TOSC1))
XTAL2: OSC.XTAL2 (3), R9.1, U1.8 (PB7(XTAL2/TOSC2))

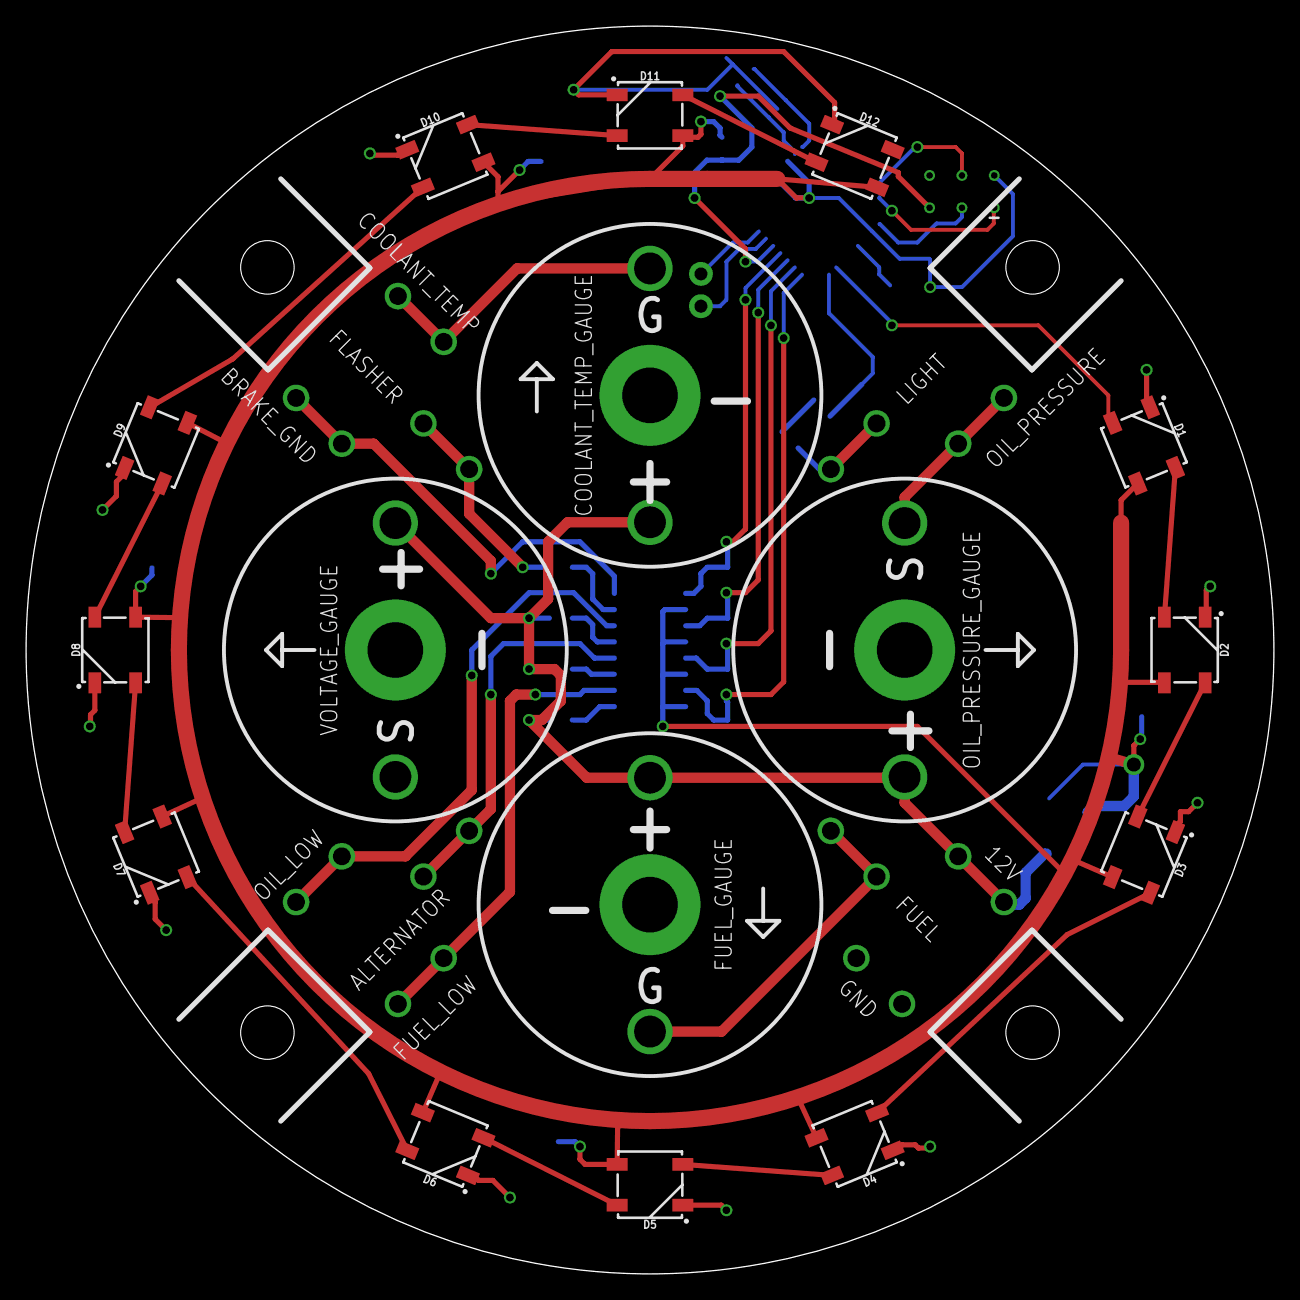
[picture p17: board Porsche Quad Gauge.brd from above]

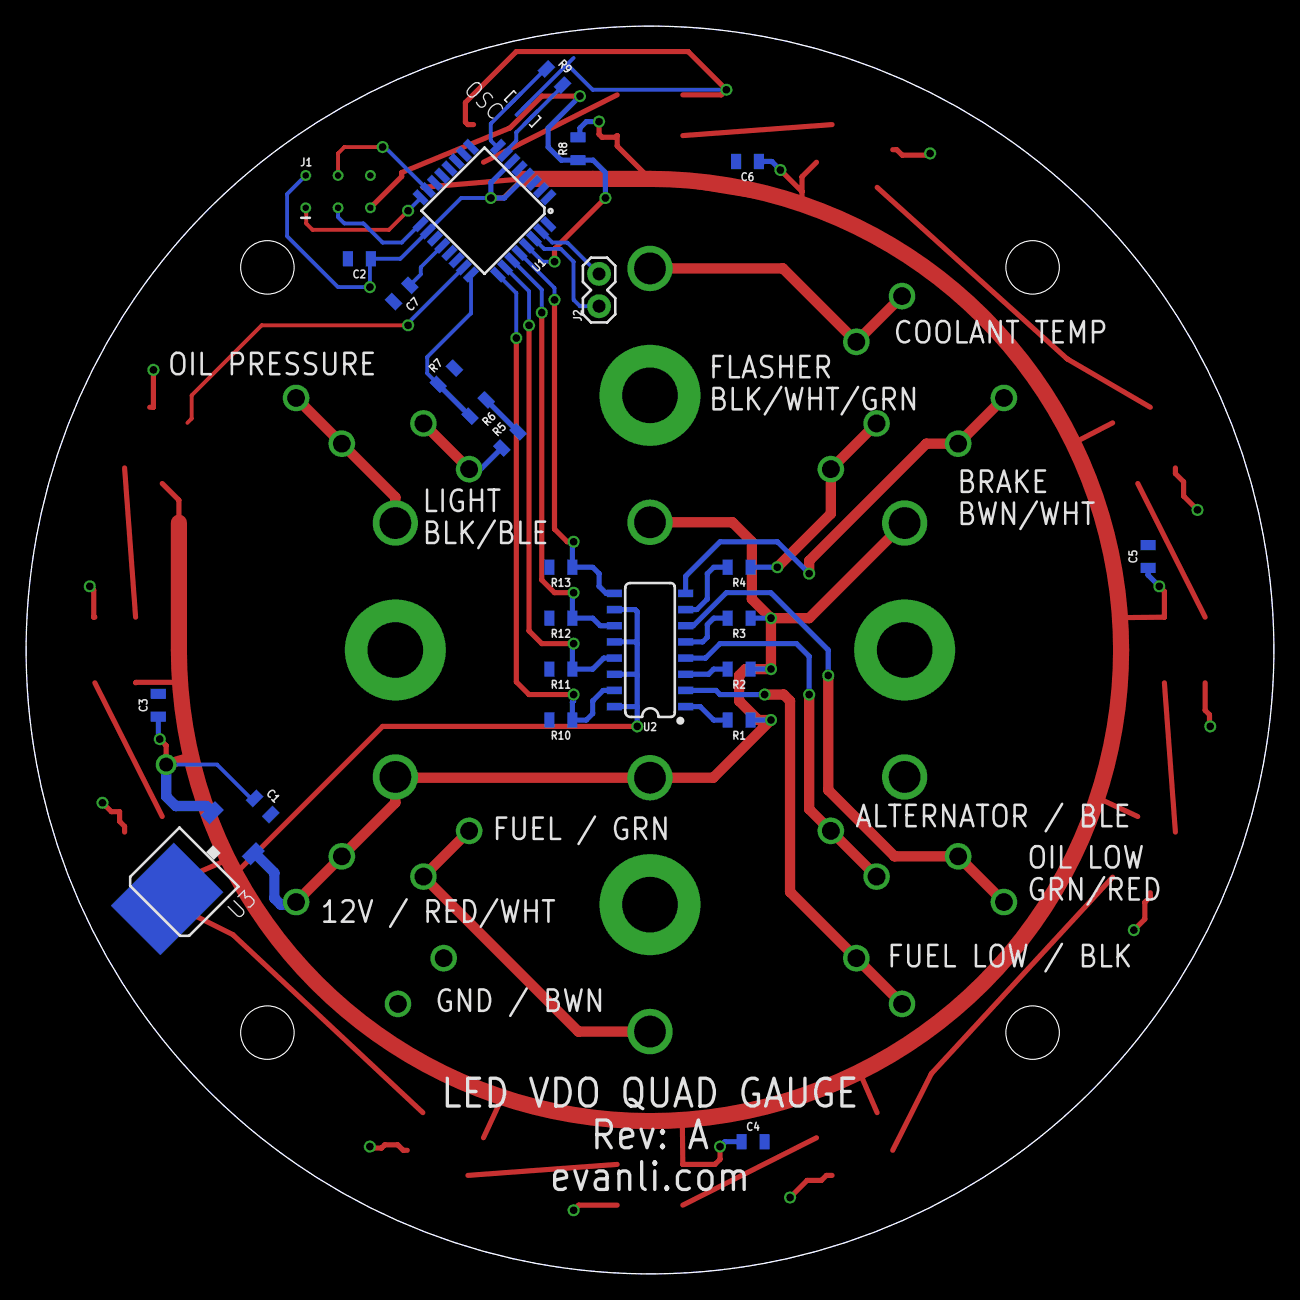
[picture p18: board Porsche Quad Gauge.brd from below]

Board: 2 copper layers, 98.0 x 98.0 mm, 53 parts (26 on the bottom side), 43 nets.

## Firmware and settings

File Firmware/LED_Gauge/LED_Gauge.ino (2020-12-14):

#include <Arduino.h>

#include <Adafruit_NeoPixel.h>

#ifdef __AVR__
  #include <avr/power.h>
#endif

#define LED_PIN 14
#define LIGHT_SENSE A1
#define FUEL_SENSE 16
#define ALTERNATOR_SENSE 17
#define OIL_SENSE 18
#define BRAKE_SENSE 19

#define MAX_BRIGHTNESS 128

#define LED_COUNT 12

// Ref: https://learn.adafruit.com/adafruit-neopixel-uberguide/arduino-library
Adafruit_NeoPixel leds = Adafruit_NeoPixel(LED_COUNT, LED_PIN, NEO_RGBW + NEO_KHZ800);

int lightSenseValue = 0;
int fuelSenseValue = 0;
int alternatorSenseValue = 0;
int oilSenseValue = 0;
int brakeSenseValue = 0;

int brightnessValue = 0;

/// RGBW seems to be GRBW
uint32_t fuelColor = leds.Color(128, 255, 0, 0); // leds.Color(255, 128, 0, 0);
uint32_t alternatorColor = leds.Color(0, 255, 0, 0);
uint32_t oilColor = leds.Color(255, 0, 0, 0);
uint32_t brakeColor = leds.Color(0, 255, 0, 0);

void setup() {

  pinMode(FUEL_SENSE, INPUT);
  pinMode(ALTERNATOR_SENSE, INPUT);
  pinMode(OIL_SENSE, INPUT);
  pinMode(BRAKE_SENSE, INPUT);

  leds.setBrightness(MAX_BRIGHTNESS);

  leds.begin();
  leds.show();
}

void loop() {

  lightSenseValue = analogRead(LIGHT_SENSE);
  fuelSenseValue = digitalRead(FUEL_SENSE);
  alternatorSenseValue = digitalRead(ALTERNATOR_SENSE);
  oilSenseValue = digitalRead(OIL_SENSE);
  brakeSenseValue = digitalRead(BRAKE_SENSE);



  brightnessValue = map(lightSenseValue, 0, 1023, 0, 128);



  for (int i = 0; i < LED_COUNT; i++) {
    leds.setPixelColor(i, leds.Color(0, 0, 0, brightnessValue));

    if (i >= 0 && i < 3 && oilSenseValue) {
      leds.setPixelColor(i, oilColor );
    }

    if (i >= 3  && i < 6 && fuelSenseValue) {
      leds.setPixelColor(i, fuelColor );
    }

    if (i >= 6 && i < 9 && alternatorSenseValue) {
      leds.setPixelColor(i, alternatorColor);
    }

    if (i >= 9 && i < 12 && brakeSenseValue) {
      leds.setPixelColor(i, brakeColor);
    }
  }


//  for (int i = 0; i < 24; i++) {
//    if (i < brightness) {
//      leds.setPixelColor(i, leds.Color(255, 0, 0));
//    } else {
//      leds.setPixelColor(i, leds.Color(0, 0, 0));
//    }
//  }

  leds.show();
  delay(50);
}

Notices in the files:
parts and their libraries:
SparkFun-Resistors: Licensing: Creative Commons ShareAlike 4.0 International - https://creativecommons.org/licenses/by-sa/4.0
